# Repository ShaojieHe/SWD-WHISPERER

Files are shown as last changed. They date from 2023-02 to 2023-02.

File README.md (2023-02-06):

# SWD-WHISPERER
Custom DAPLink Hardware Design using AIR32F103Cx, This Version of hardware support SWD, JTAG, USB CDC, **ITM Trace/SWO**

Also this repo contain an [addon project](https://github.com/ShaojieHe/SWD-WHISPERER/tree/3225_crystal/standardJTAG_ADAPTER) to convert custom pinout to standard JTAG pinout for better debugging experience.

Licenced under CERN OHL v2 Permissive

## Pre-Built Custom DAPLink Firmware

[Github Repo](https://github.com/ShaojieHe/DAPLink-Extra)

[AIR32F10x Pre-Release](https://github.com/ShaojieHe/DAPLink-Extra/releases/tag/air32-pre-release)

## PCB Schematic
[Schematic](https://github.com/ShaojieHe/SWD-WHISPERER/blob/3225_crystal/DAPLink/air.pdf)

## PCB 3D Image

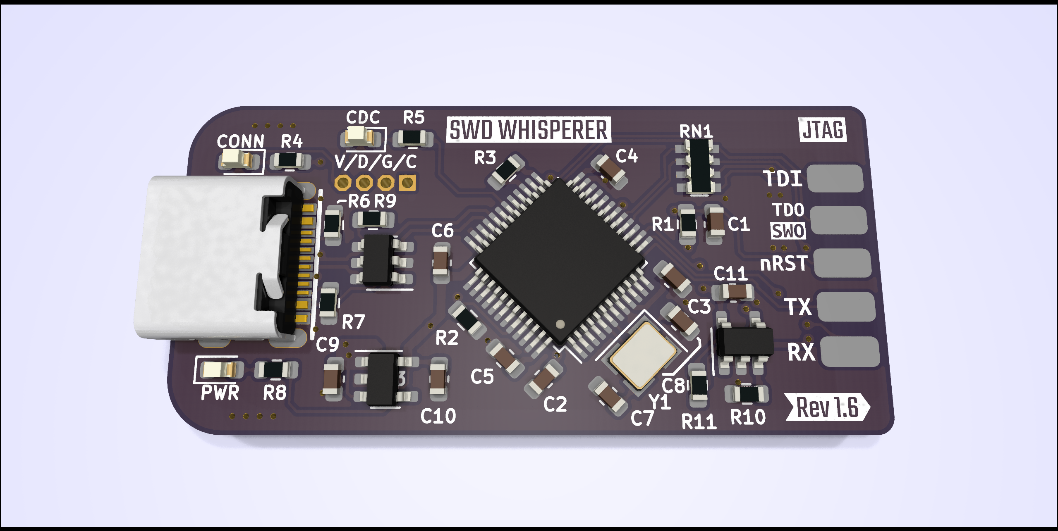
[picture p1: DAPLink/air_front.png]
AIR_FRONT


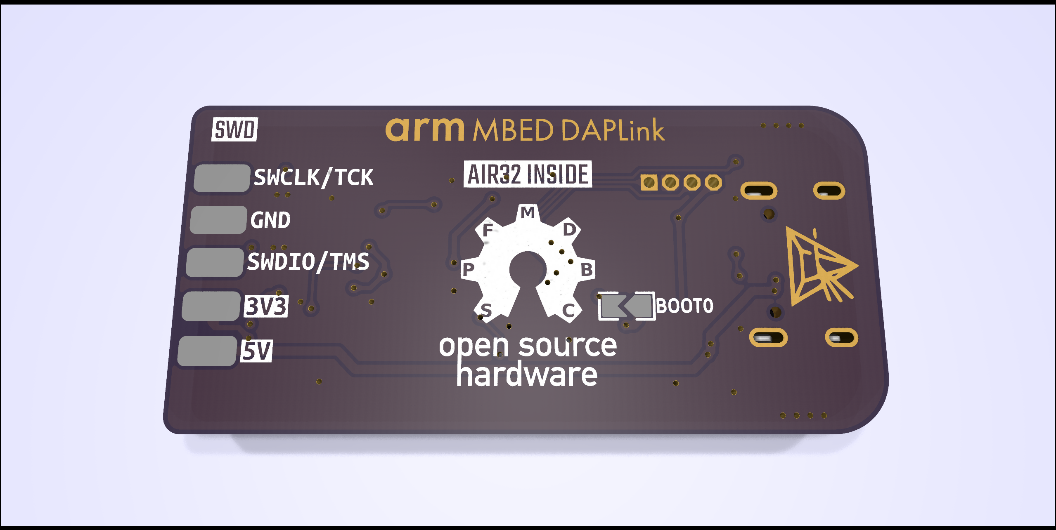
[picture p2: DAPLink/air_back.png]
AIR_BACK


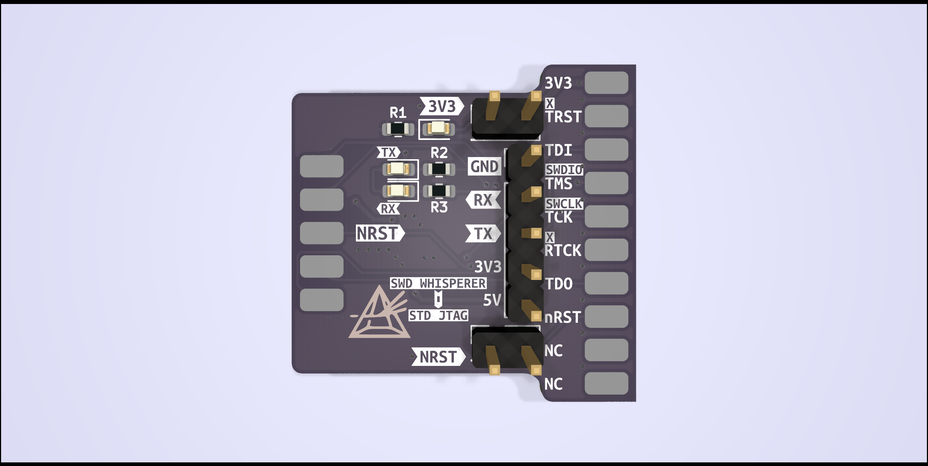
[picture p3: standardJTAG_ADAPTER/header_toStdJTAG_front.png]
Conv_Front


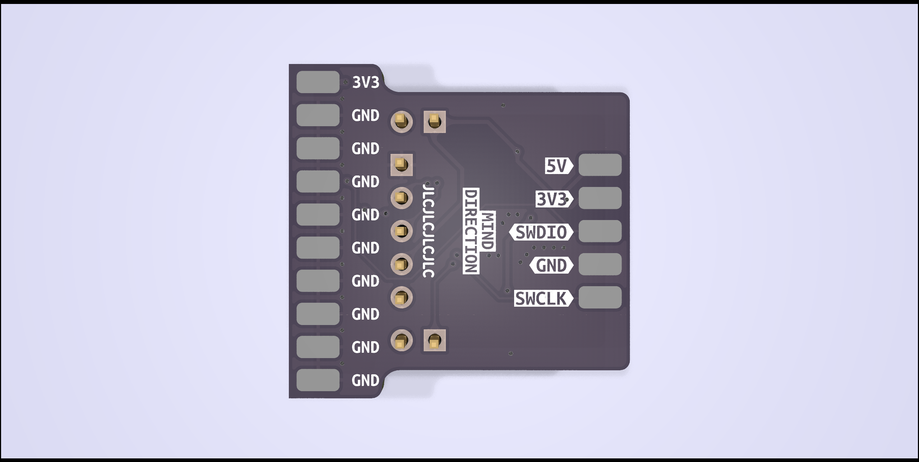
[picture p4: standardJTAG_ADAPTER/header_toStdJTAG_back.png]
Conv_Back


## How to Modify

This is an KiCad Project Design on version 6.0.9, You need an KiCad's Version > 6 to open it and play it around :)

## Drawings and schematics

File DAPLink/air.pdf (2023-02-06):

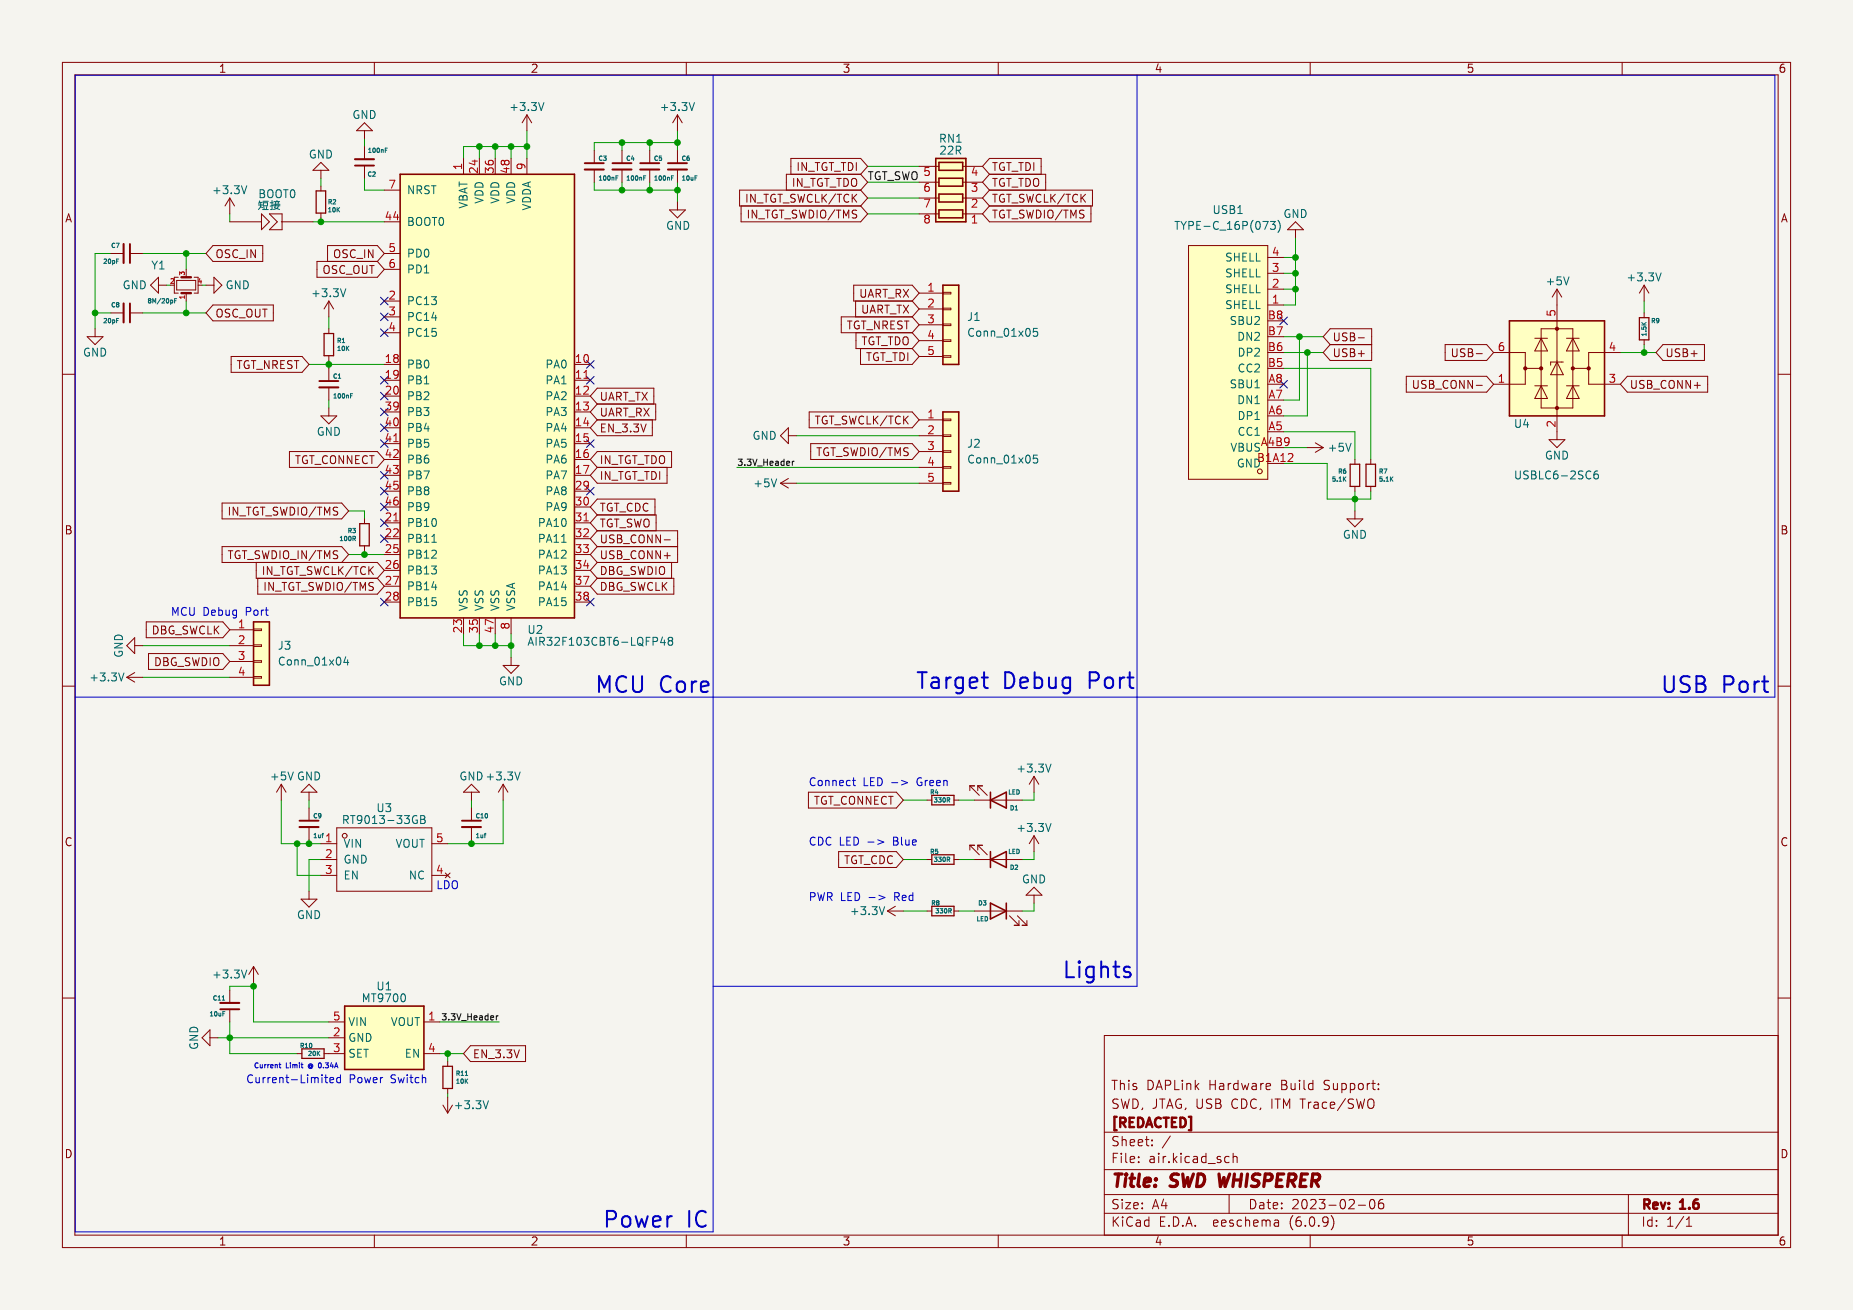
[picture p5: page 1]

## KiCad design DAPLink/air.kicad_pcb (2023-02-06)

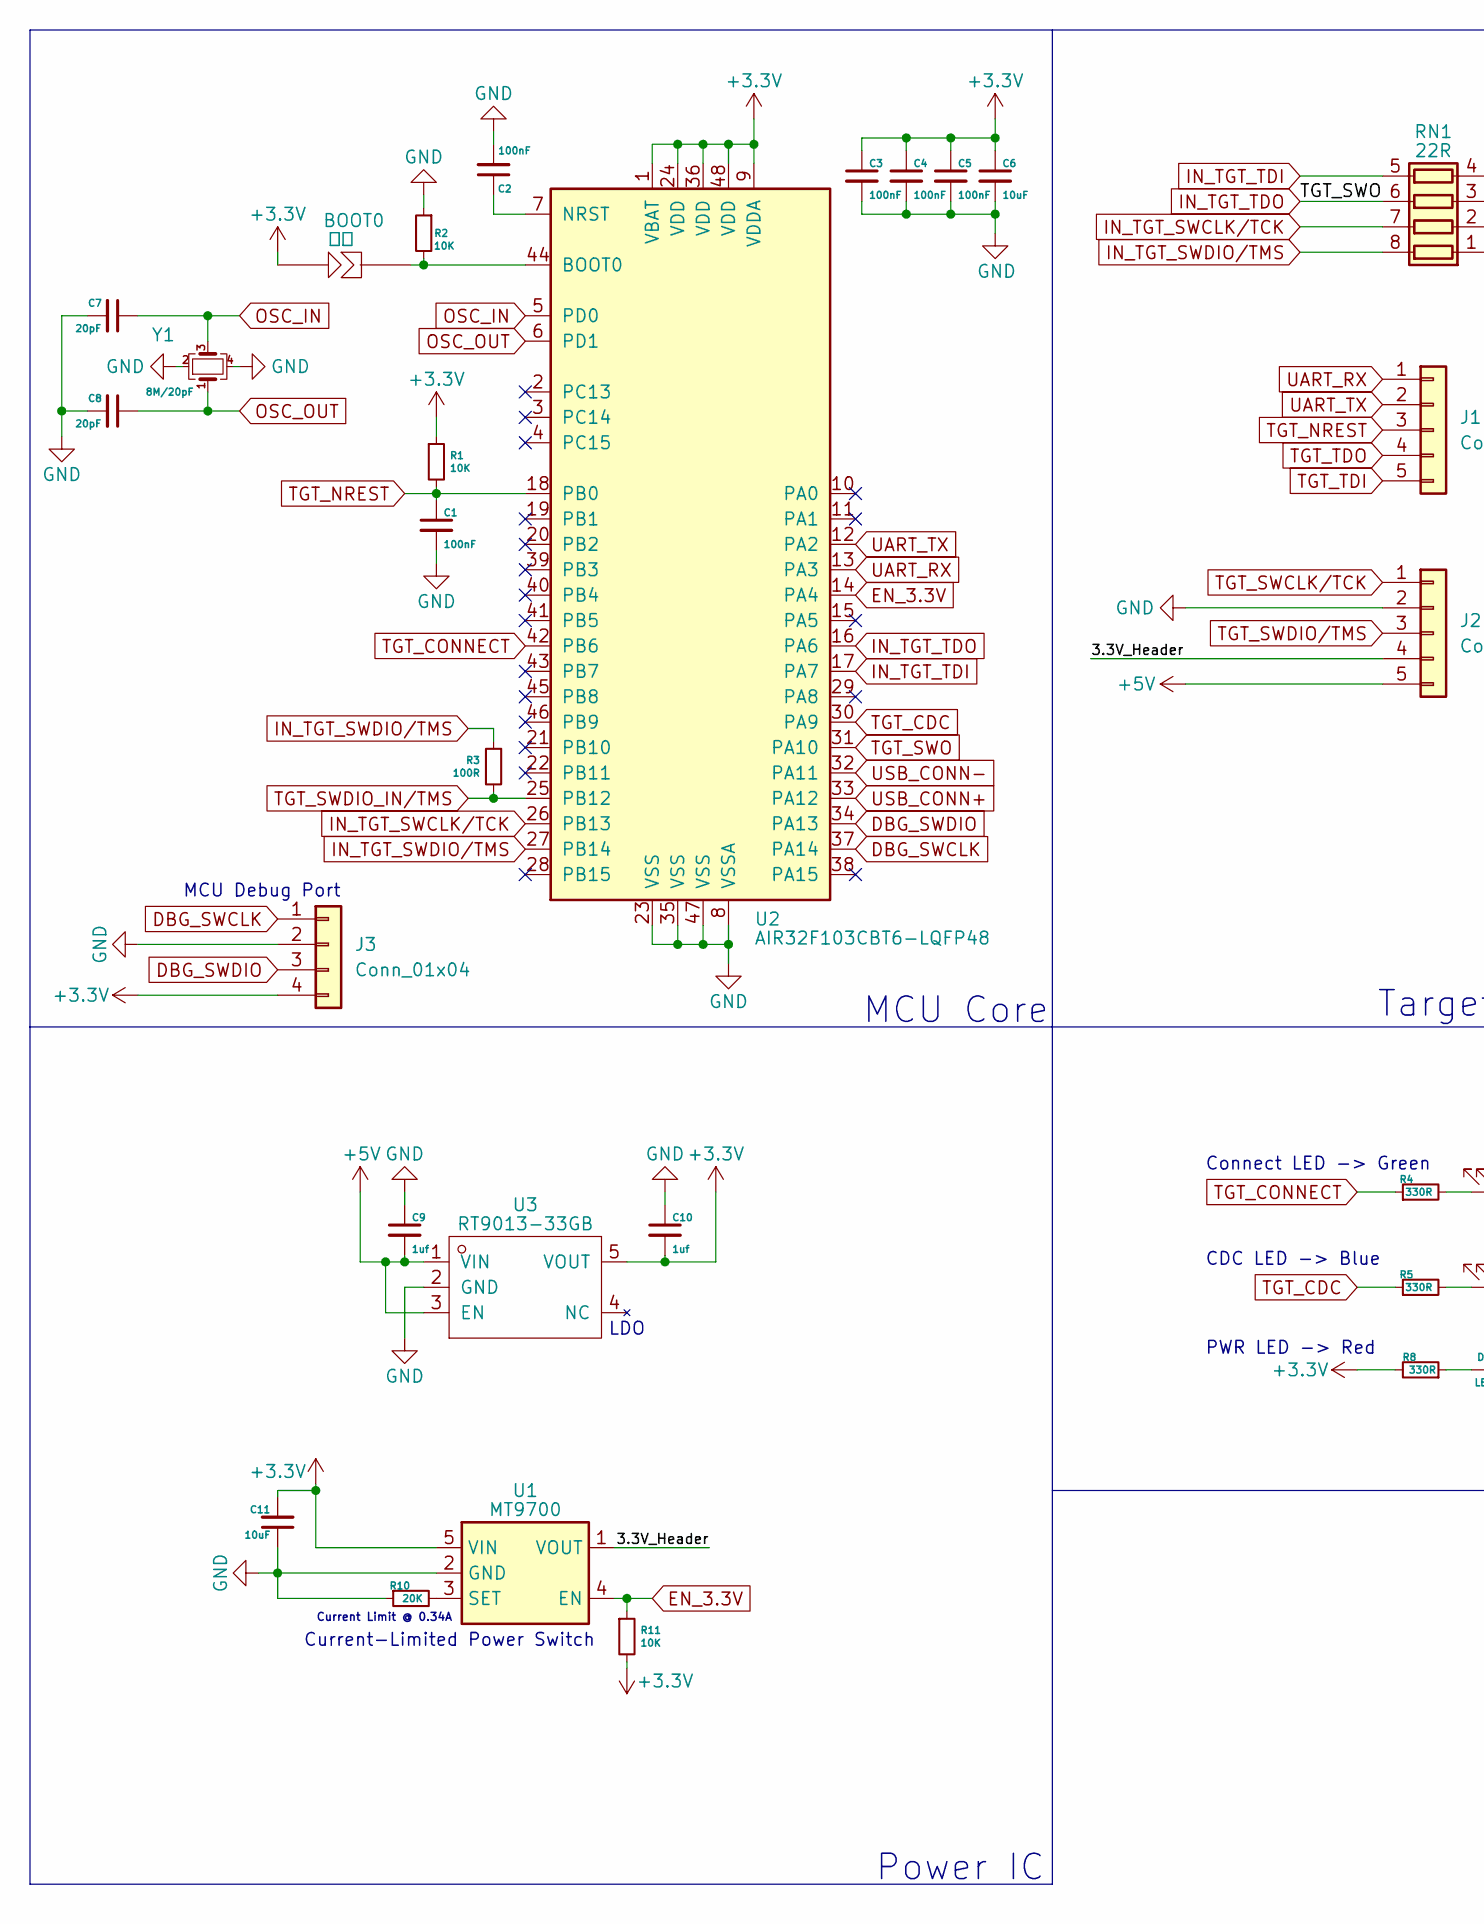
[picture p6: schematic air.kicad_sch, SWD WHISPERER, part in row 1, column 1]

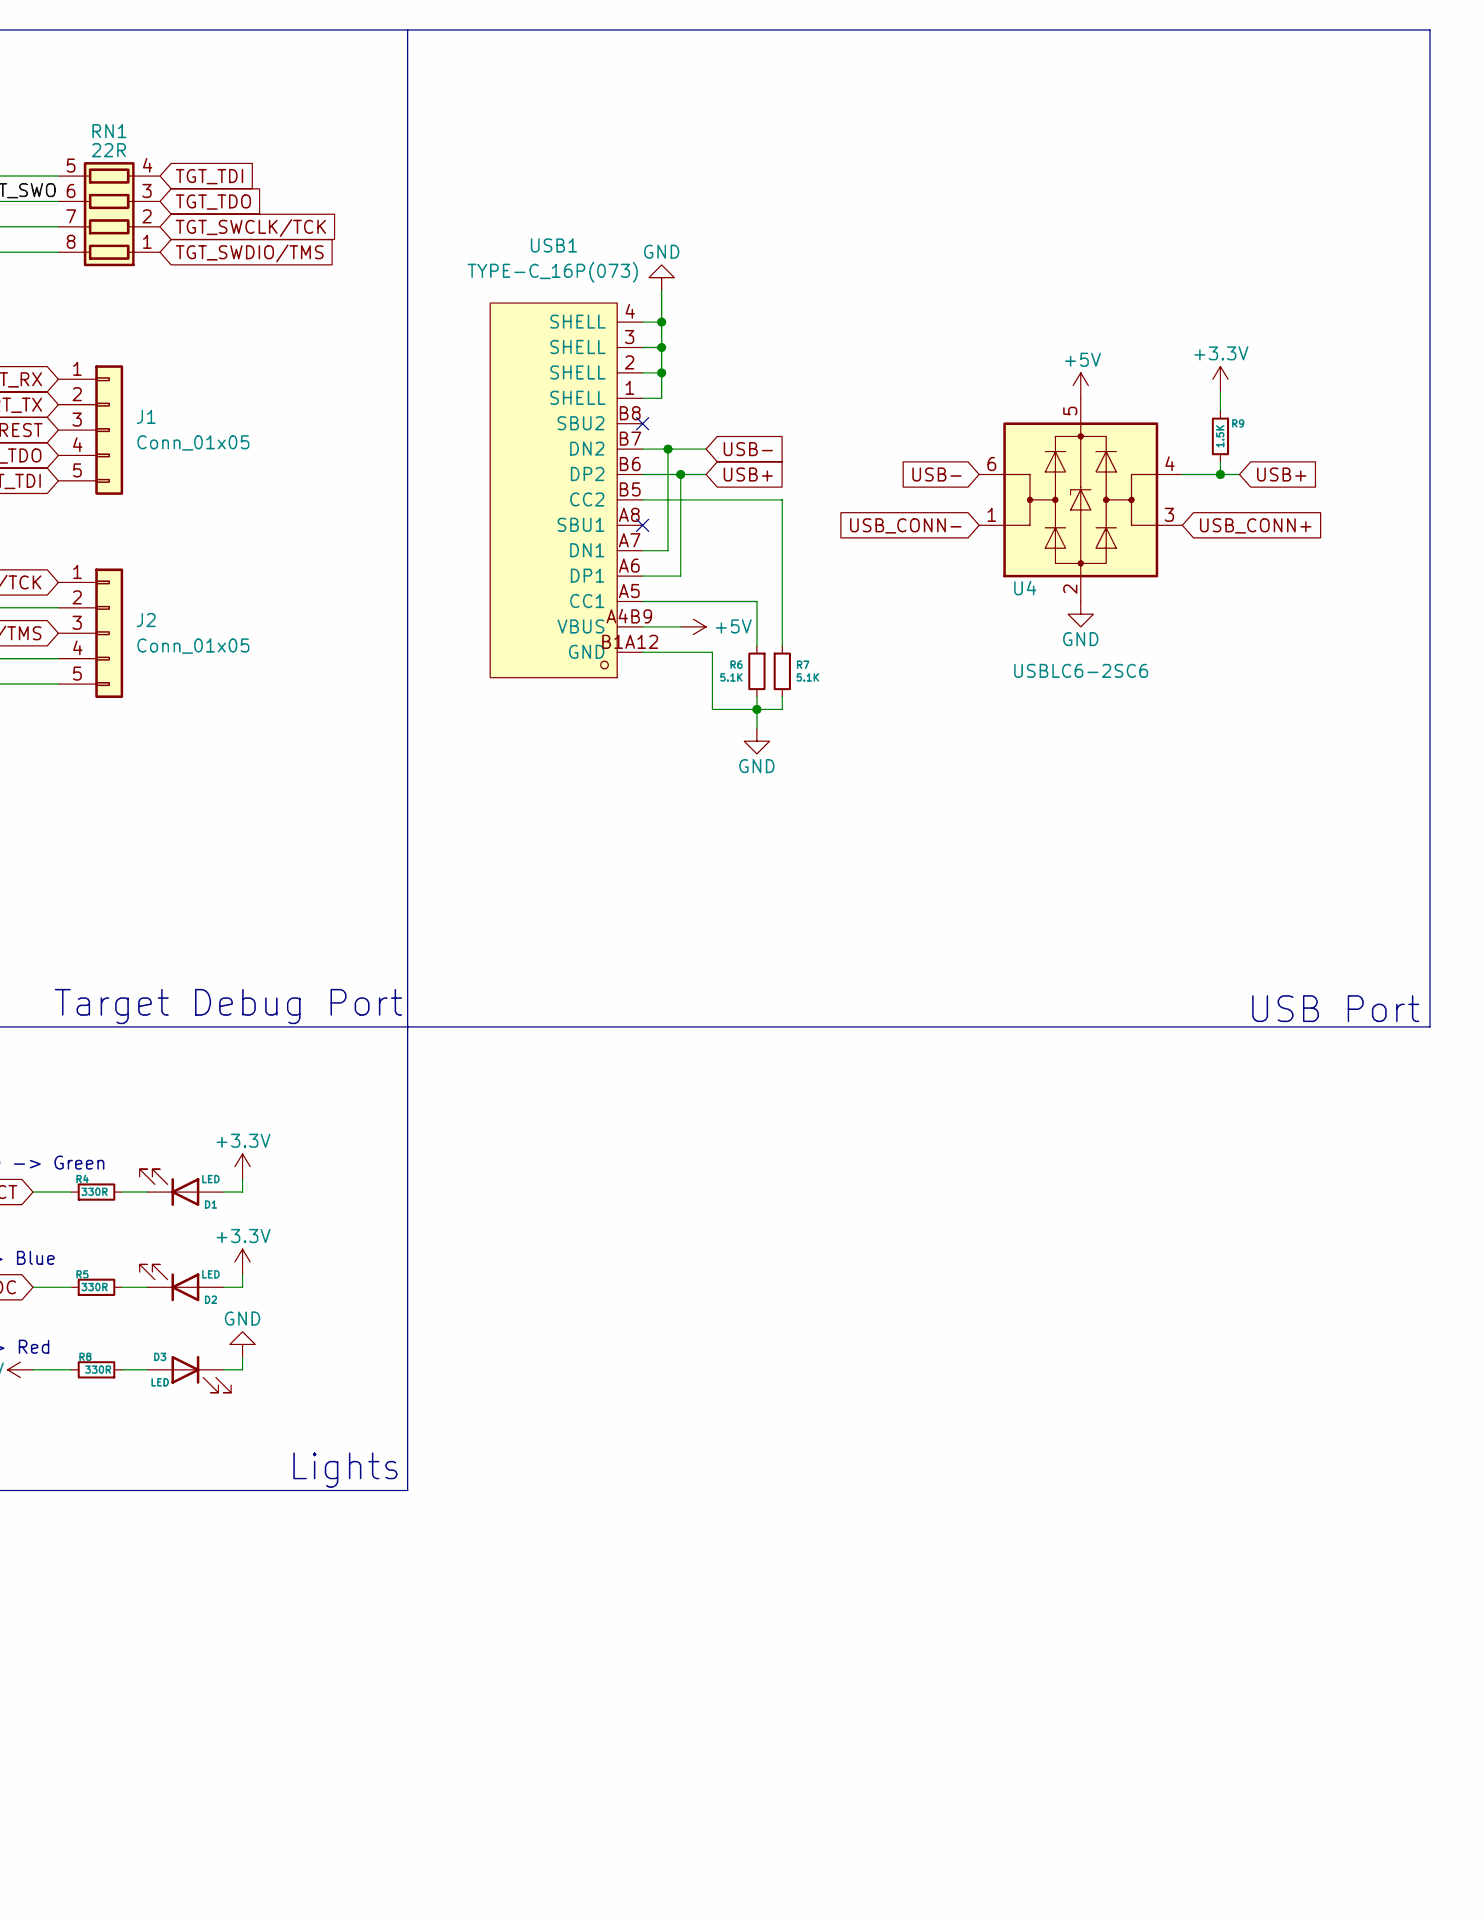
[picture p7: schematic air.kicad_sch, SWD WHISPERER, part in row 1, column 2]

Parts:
BOOT0: 短接; Short_0603
C1, C2, C3, C4, C5: 100nF; C_0603_1608Metric
C6, C11: 10uF; C_0603_1608Metric
C7, C8: 20pF; C_0603_1608Metric
C9, C10: 1uf; C_0603_1608Metric
D1, D2, D3: LED; LED_0603_1608Metric
J1, J2: Conn_01x05; 2.54_1X5
J3: Conn_01x04; PinHeader_1x04_P1.27mm_Vertical
R1, R2, R11: 10K; R_0603_1608Metric
R3: 100R; R_0603_1608Metric
R4, R5, R8: 330R; R_0603_1608Metric
R6, R7: 5.1K; R_0603_1608Metric
R9: 1.5K; R_0603_1608Metric
R10: 20K; R_0603_1608Metric
RN1: 22R; R_Array_Convex_4x0603
U1: MT9700; SOT-23-5
U2: AIR32F103CBT6-LQFP48; LQFP-48_7x7mm_P0.5mm
U3: RT9013-33GB; SOT-23-5
U4: USBLC6-2SC6; SOT-23-6
USB1: TYPE-C_16P(073); USB-C-SMD_TYPE-C16PIN_C668624
Y1: 8M/20pF; Crystal_SMD_3225-4Pin_3.2x2.5mm

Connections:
+3.3V: BOOT0.1, C3.1, C4.1, C5.1, C6.1, C10.2, C11.2, D1.2 (A), D2.2 (A), J3.4, R1.1, R8.2, R9.1, R11.2, U1.5 (VIN), U2.1 (VBAT), U2.9 (VDDA), U2.24 (VDD), U2.36 (VDD), U2.48 (VDD), U3.5 (VOUT)
+5V: C9.2, J2.5, U3.1 (VIN), U3.3 (EN), U4.5 (VBUS), USB1.A4B9 (VBUS)
/3.3V_Header: J2.4, U1.1 (VOUT)
DBG_SWCLK: J3.1, U2.37 (PA14)
DBG_SWDIO: J3.3, U2.34 (PA13)
EN_3.3V: R11.1, U1.4 (EN), U2.14 (PA4)
GND: C1.2, C2.2, C3.2, C4.2, C5.2, C6.2, C7.2, C8.2, C9.1, C10.1, C11.1, D3.1 (K), J2.2, J3.2, R2.1, R6.2, R7.2, R10.1, U1.2 (GND), U2.8 (VSSA), U2.23 (VSS), U2.35 (VSS), U2.47 (VSS), U3.2 (GND), U4.2 (GND), USB1.1 (SHELL), USB1.2 (SHELL), USB1.3 (SHELL), USB1.4 (SHELL), USB1.A1B12 (GND), USB1.B1A12 (GND), Y1.2, Y1.4
IN_TGT_SWCLK/TCK: RN1.7 (R2.2), U2.26 (PB13)
IN_TGT_SWDIO/TMS: R3.1, RN1.8 (R1.2), U2.27 (PB14)
IN_TGT_TDI: RN1.5 (R4.2), U2.17 (PA7)
IN_TGT_TDO: RN1.6 (R3.2), U2.16 (PA6), U2.31 (PA10)
unnamed: BOOT0.2, R2.2, U2.44 (BOOT0)
unnamed: C2.1, U2.7 (NRST)
unnamed: D1.1 (K), R4.2
unnamed: D2.1 (K), R5.2
unnamed: D3.2 (A), R8.1
unnamed: R6.1, USB1.A5 (CC1)
unnamed: R7.1, USB1.B5 (CC2)
unnamed: R10.2, U1.3 (SET)
OSC_IN: C7.1, U2.5 (PD0), Y1.3
OSC_OUT: C8.1, U2.6 (PD1), Y1.1
TGT_CDC: R5.1, U2.30 (PA9)
TGT_CONNECT: R4.1, U2.42 (PB6)
TGT_NREST: C1.1, J1.3, R1.2, U2.18 (PB0)
TGT_SWCLK/TCK: J2.1, RN1.2 (R2.1)
TGT_SWDIO_IN/TMS: R3.2, U2.25 (PB12)
TGT_SWDIO/TMS: J2.3, RN1.1 (R1.1)
TGT_TDI: J1.5, RN1.4 (R4.1)
TGT_TDO: J1.4, RN1.3 (R3.1)
UART_RX: J1.1, U2.13 (PA3)
UART_TX: J1.2, U2.12 (PA2)
USB+: R9.2, U4.4 (I/O2), USB1.A6 (DP1), USB1.B6 (DP2)
USB-: U4.6 (I/O1), USB1.A7 (DN1), USB1.B7 (DN2)
USB_CONN+: U2.33 (PA12), U4.3 (I/O2)
USB_CONN-: U2.32 (PA11), U4.1 (I/O1)

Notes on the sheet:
CDC LED -> Blue
Target Debug Port
Lights
LDO
USB Port
MCU Core
Power IC
Current Limit @ 0.34A
Current-Limited Power Switch
PWR LED -> Red
Connect LED -> Green
MCU Debug Port

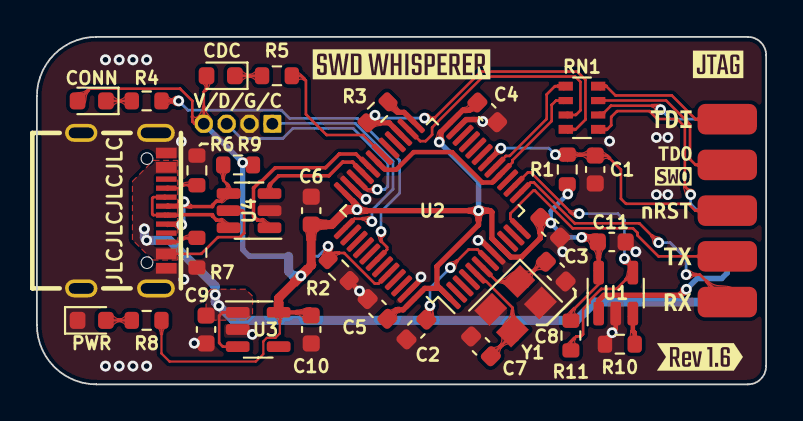
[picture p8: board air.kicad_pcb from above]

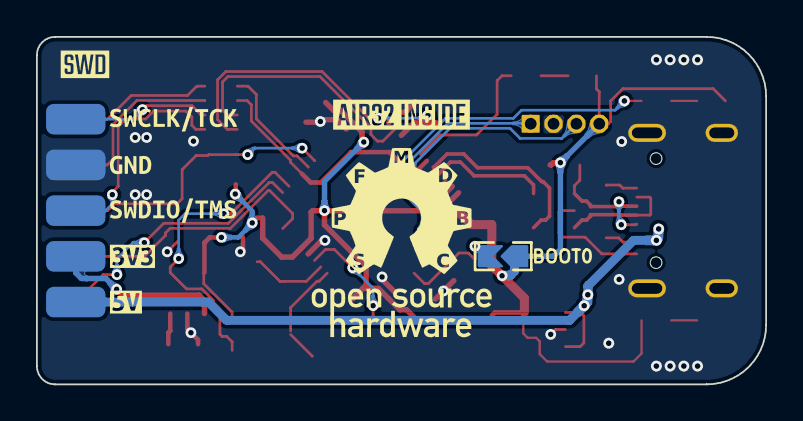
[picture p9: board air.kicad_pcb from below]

Board: 2 copper layers, 40.5 x 19.3 mm, 52 parts (9 on the bottom side), 35 nets.

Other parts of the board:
kibuzzard-63E0775E: G***; kibuzzard-63E0775E
kibuzzard-63E0777D: G***; kibuzzard-63E0777D
kibuzzard-63E07756: G***; kibuzzard-63E07756
kibuzzard-63E07768: G***; kibuzzard-63E07768
kibuzzard-63E07774: G***; kibuzzard-63E07774
kibuzzard-637AECE1: G***; kibuzzard-637AECE1
kibuzzard-637AED1A: G***; kibuzzard-637AED1A
kibuzzard-6354CCE5: G***; kibuzzard-6354CCE5
kibuzzard-6354CCEF: G***; kibuzzard-6354CCEF
kibuzzard-6354CCF5: G***; kibuzzard-6354CCF5
kibuzzard-6354CD34: G***; kibuzzard-6354CD34
kibuzzard-6354CD45: G***; kibuzzard-6354CD45
kibuzzard-6354CD83: G***; kibuzzard-6354CD83
kibuzzard-6354CD88: G***; kibuzzard-6354CD88
kibuzzard-6354CDA6: G***; kibuzzard-6354CDA6
kibuzzard-6354D1FB: G***; kibuzzard-6354D1FB

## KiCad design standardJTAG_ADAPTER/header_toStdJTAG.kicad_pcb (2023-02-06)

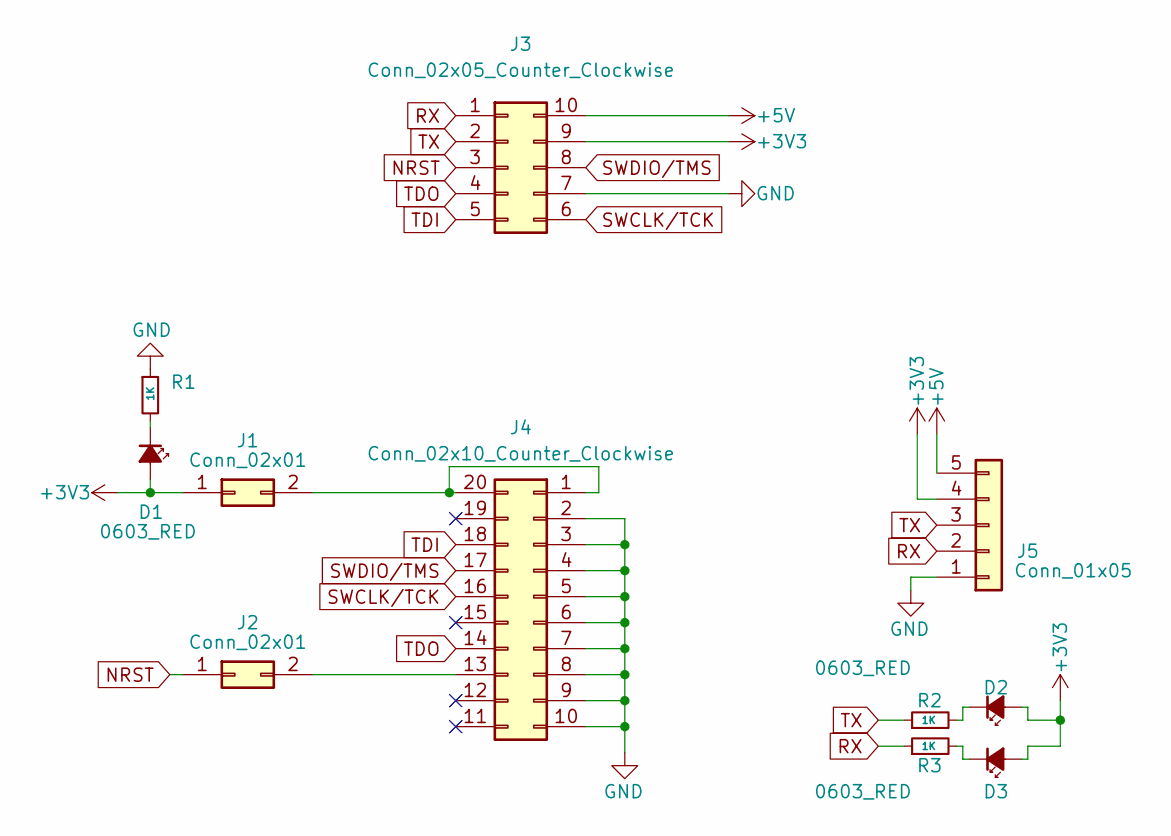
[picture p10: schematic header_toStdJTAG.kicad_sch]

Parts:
D1, D2, D3: 0603_RED; LED_0603_1608Metric
J1, J2: Conn_02x01; PinHeader_2x01_P2.54mm_Vertical
J3: Conn_02x05_Counter_Clockwise; 2.54_2X5
J4: Conn_02x10_Counter_Clockwise; 2.54_2X10
J5: Conn_01x05; PinHeader_1x05_P2.54mm_Vertical
R1, R2, R3: 1K; R_0603_1608Metric

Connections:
+3V3: D1.2 (A), D2.2 (A), D3.2 (A), J1.1, J3.9, J5.4
+5V: J3.10, J5.5
GND: J3.7, J4.2, J4.3, J4.4, J4.5, J4.6, J4.7, J4.8, J4.9, J4.10, J5.1, R1.1
NRST: J2.1, J3.3
unnamed: D1.1 (K), R1.2
unnamed: D2.1 (K), R2.2
unnamed: D3.1 (K), R3.2
unnamed: J1.2, J4.1, J4.20
unnamed: J2.2, J4.13
RX: J3.1, J5.2, R3.1
SWCLK/TCK: J3.6, J4.16
SWDIO/TMS: J3.8, J4.17
TDI: J3.5, J4.18
TDO: J3.4, J4.14
TX: J3.2, J5.3, R2.1

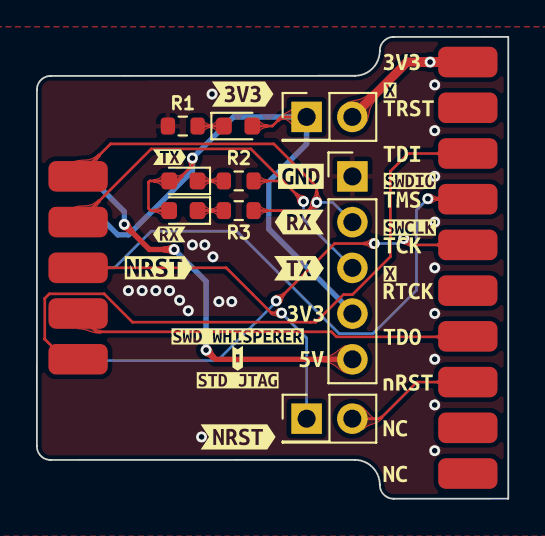
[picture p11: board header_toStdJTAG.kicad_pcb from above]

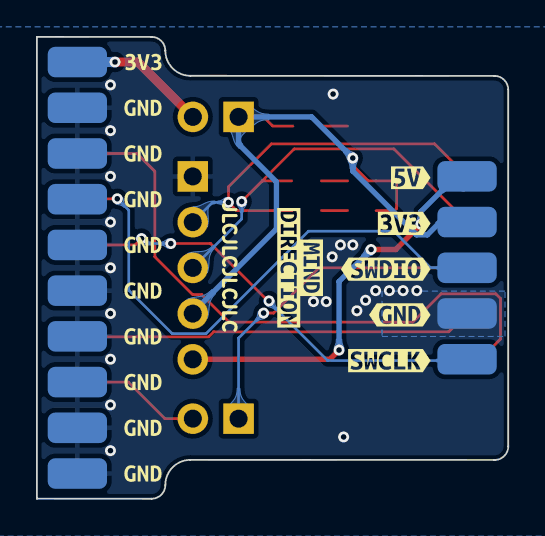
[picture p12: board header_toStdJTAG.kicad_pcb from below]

Board: 2 copper layers, 26.2 x 25.7 mm, 56 parts (18 on the bottom side), 15 nets.

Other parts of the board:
e: MY_LOGO
kibuzzard-632C5A4E: G***; kibuzzard-632C5A4E
kibuzzard-632C5A5B: G***; kibuzzard-632C5A5B
kibuzzard-632C5A6C: G***; kibuzzard-632C5A6C
kibuzzard-632C5A7C: G***; kibuzzard-632C5A7C
kibuzzard-632C5A8E: G***; kibuzzard-632C5A8E
kibuzzard-632C5A78: G***; kibuzzard-632C5A78
kibuzzard-632C5AAA: G***; kibuzzard-632C5AAA
kibuzzard-632C5AB4: G***; kibuzzard-632C5AB4
kibuzzard-632C5ABC: G***; kibuzzard-632C5ABC
kibuzzard-632C5B86: G***; kibuzzard-632C5B86
kibuzzard-632C5BCD: G***; kibuzzard-632C5BCD
kibuzzard-632C5CBE: G***; kibuzzard-632C5CBE
kibuzzard-632C5D1, kibuzzard-632C5D2, kibuzzard-632C5D3, kibuzzard-632C5D4, kibuzzard-632C5D5, kibuzzard-632C5D6, kibuzzard-632C5D7, kibuzzard-632C5D8, kibuzzard-632C5D89: G***; kibuzzard-632C5D89
kibuzzard-632C5D32: G***; kibuzzard-632C5D32
kibuzzard-632C5EE0: G***; kibuzzard-632C5EE0
kibuzzard-632C5EFB: G***; kibuzzard-632C5EFB
kibuzzard-632C5F3E: G***; kibuzzard-632C5F3E
kibuzzard-632C57D4: G***; kibuzzard-632C57D4
kibuzzard-632C57F8: G***; kibuzzard-632C57F8
kibuzzard-632C60B1: G***; kibuzzard-632C60B1
kibuzzard-632C60B5: G***; kibuzzard-632C60B5
kibuzzard-632C60E7: G***; kibuzzard-632C60E7
kibuzzard-632C575C: G***; kibuzzard-632C575C
kibuzzard-632C580A: G***; kibuzzard-632C580A
kibuzzard-632C584F: G***; kibuzzard-632C584F
kibuzzard-632C5768: G***; kibuzzard-632C5768
kibuzzard-632C5841: G***; kibuzzard-632C5841
kibuzzard-632C5933, kibuzzard-632C5933#2: G***; kibuzzard-632C5933
kibuzzard-632C6056: G***; kibuzzard-632C6056
kibuzzard-632C6067: G***; kibuzzard-632C6067
kibuzzard-632C6200, kibuzzard-632C6200#2: G***; kibuzzard-632C6200
kibuzzard-6336E20B: G***; kibuzzard-6336E20B
kibuzzard-6336E28C: G***; kibuzzard-6336E28C
kibuzzard-6336E204: G***; kibuzzard-6336E204

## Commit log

2022-10-23 V1.3版本更新
    第一版本更新 之前的都没包含在里面
    [air.kicad_pcb, air.kicad_sch]
2022-10-23 V1.3 3225晶振版本
    [air.kicad_pcb, air.kicad_sch]
2022-11-21 更新了SWO的硬件功能 从该板开始 可能不兼容上一代的固件
    [air.kicad_pcb, air.kicad_sch]
2022-11-26 v1.5 added series resistor on debug lines
    [air.kicad_pcb, air.kicad_sch]
2022-12-25 1.6 Redesign And Add Anti Reverse Current
    [air.kicad_pcb, air.kicad_sch]
2023-02-06 still 1.6 but contain some fix to publish work
    [air.kicad_pcb, air.kicad_sch]
2023-02-06 创建了 README.md
2023-02-06 添加了 CERN OHL v2 Permissive 开源协议
2023-02-06 add schematic of v1.6
2023-02-06 moved gerber file from repo to release
2023-02-06 更新了 README
2023-02-06 reloacted file to include new addon project
    [air.kicad_pcb, air.kicad_sch]
2023-02-06 add an addon project to include standardJTAG_Adapter
    [header_toStdJTAG.kicad_pcb, header_toStdJTAG.kicad_sch]
2023-02-06 更新了README
2023-02-06 replace Font with specimen/Teko
    [air.kicad_pcb]
